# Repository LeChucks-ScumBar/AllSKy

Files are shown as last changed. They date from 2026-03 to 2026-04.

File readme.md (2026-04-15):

# AllSky to Go STSCI Waldbröl
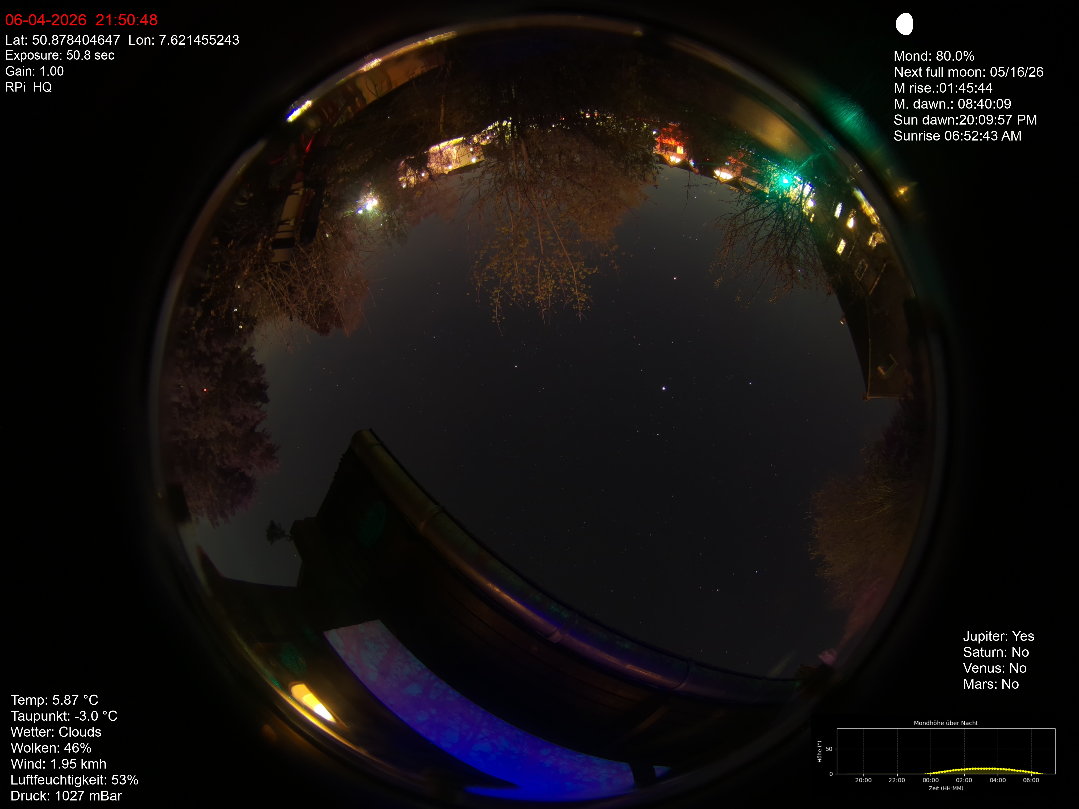
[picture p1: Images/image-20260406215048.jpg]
single image with data


## how to install

copy all files in the home Directory. 

## Setup crontab

````
crontab -e
````

add this two cronjobs

```
*/30 * * * * python ~/allsky/gps_coords.py
0 */1 * * * /home/raspberry/allsky/scripts/moon_height_venv.sh
```

## install skyfield for moon diagram

```
pip3 install skyfield matplotlib numpy
```

if this not work use a virtual environment
```
sudo apt install python3-venv
mkdir -p ~/allsky/venv
python3 -m venv ~/allsky/venv
source ~/allsky/venv/bin/activate
pip install skyfield requests
```

test the moon_height.py script
```
python ~/allsky/scripts/moon_height.py
```
Change crontab entry. moon_height_venv.sh use For skyfield the new use a virtual enviroment 
```
crontab -e
0 */1 * * * /home/raspberry/allsky/scripts/moon_height_venv.sh

```

if this is not working you can use the quick and dirty Methode

```
pip install skyfield --break-system-packages
```

Now you can overlay this image with your camera Picture. Go to your Webbrowser and to your allsky Webpage. Go to the "Overlay Editor" and Chose "add Existing Image Field". In the image menue you can select moon_height.png.

## install gps
For installing the gps-module I have used the install manuel from Allsky_go
[AllskyGo_GPS_install](https://github.com/Chrise-2000/Allsky_Go/blob/main/C_Installation%20Manual%20v3.0.pdf)
Use a usb-gps-module were you can connect with your pi. IF you don´t want to use a or you haven`t an gps-module enter you coordinates in ~/allskygps_coords.txt

## weather data
For overlay weather data I`ve used the open weather module from allsky-modules. You need only a open-weather apy-key. Registration at https://openweathermap.org/ is free, and data can be accessed up to 3,600 times a day at no additional cost.

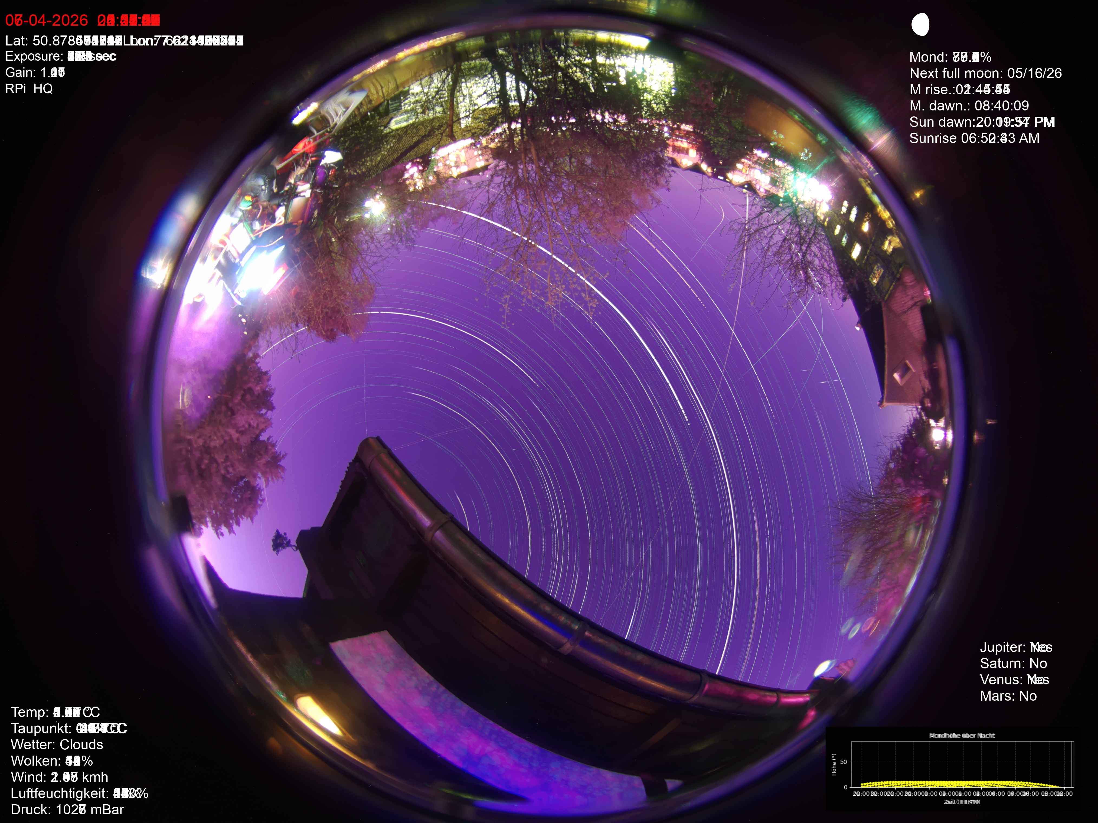
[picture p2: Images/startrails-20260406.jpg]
Startrail

## Material
- [RAspberry Pi 5 4 GB RAM](https://www.amazon.de/Raspberry-Pi-SC1111-5-4Gb/dp/B0CK3L9WD3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)
- [Raspberry PI HQ Camera](https://www.amazon.de/dp/B0BHF4D1QY/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)
- [Camera cable](https://www.amazon.de/dp/B0DHVGGY24/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)
- [Fisheye M12 1,56 mm](https://botland.de/kameraobjektive-fur-raspberry-pi/17066-fisheye-m12-156-mm-objektiv-mit-adapter-fur-raspberry-pi-kamera-arducam-ln031-5904422378349.html)
- [active cooling](https://www.amazon.de/GeeekPi-Aktiver-Raspberry-Aluminum-K%C3%BChlk%C3%B6rper/dp/B0CNVDF2MC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)

or use the POE HAT

- [POE](https://www.amazon.de/Waveshare-HAT-Power-Over-Ethernet/dp/B0CV4MYGMF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)
- [256GB SD card](https://www.amazon.de/dp/B0BFHHKHFK/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) 32GB is also OK
- [AllSky Dome](https://www.amazon.de/dp/B01MZGX7XY/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)
  
## External Links 
External Projects Links were I have used for this project

[Original AllSky](https://github.com/AllskyTeam/allsky)

[AllSky Modules](https://github.com/AllskyTeam/allsky-modules)

[AllSky Go](https://github.com/Chrise-2000/Allsky_Go)

## Images
Version 1 Top, 125 KG Rohr, with ZWO715MC
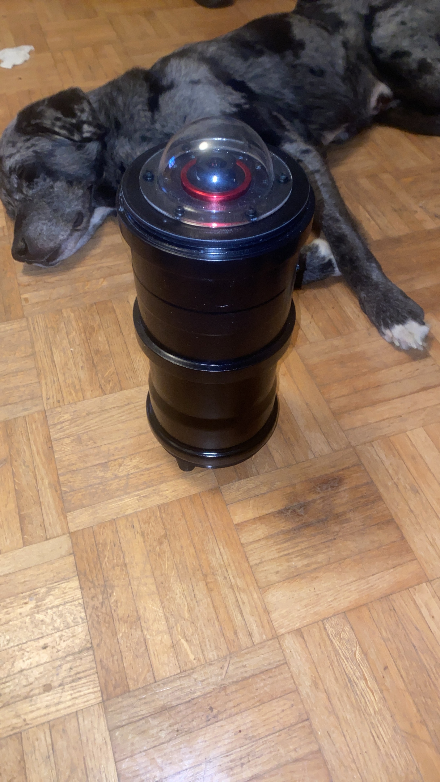
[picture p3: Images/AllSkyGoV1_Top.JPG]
Version 1 Top, 125 KG Rohr, with ZWO715MC


Version 1 Bottom, 125 KG Rohr with ZWO715MC
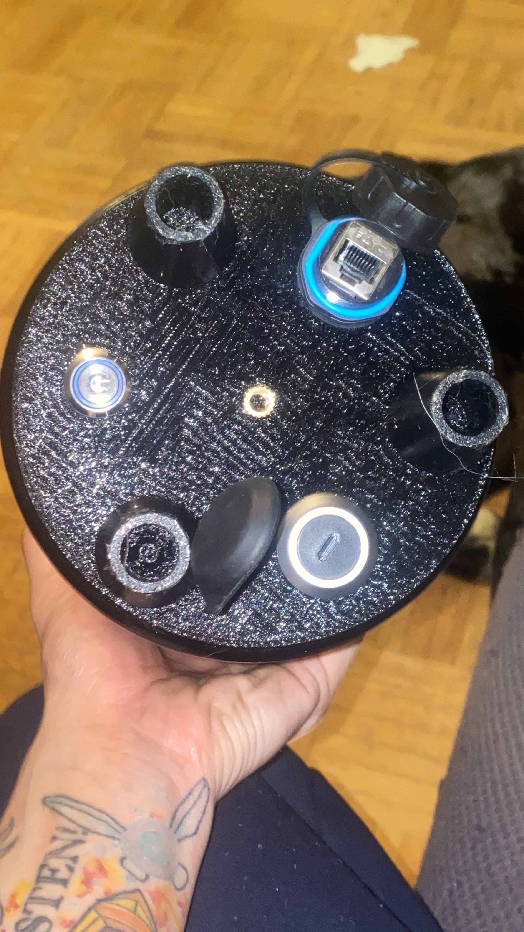
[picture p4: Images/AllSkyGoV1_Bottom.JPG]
Version 1 Bottom, 125 KG Rohr with ZWO715MC


Version 2 with bigger battery and PiHQ camera
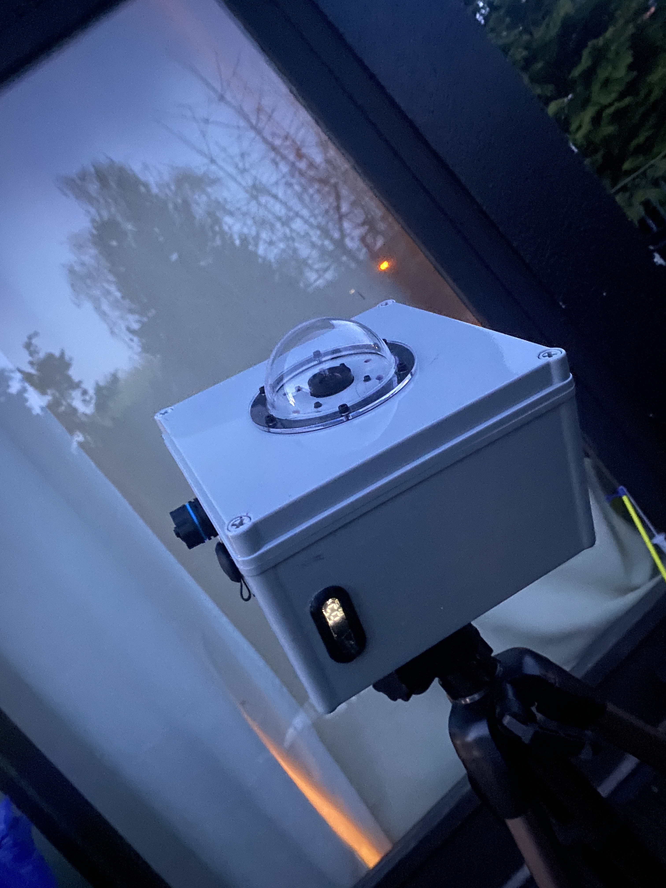
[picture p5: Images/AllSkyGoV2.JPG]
Version 2 with bigger battery and PiHQ camera


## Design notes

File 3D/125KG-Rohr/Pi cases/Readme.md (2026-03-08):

##Pi Cases from makerworld

- Raspberry Pi 5 MACH 1 Gehäuse [inline-style link](https://makerworld.com/de/models/648246-raspberry-pi-5-mach-1-case?from=search#profileId-575928)

- Minimales Raspberry Pi 5 Gehäuse [inline-style link](https://makerworld.com/de/models/106015-minimal-raspberry-pi-5-case?from=search#profileId-456882)

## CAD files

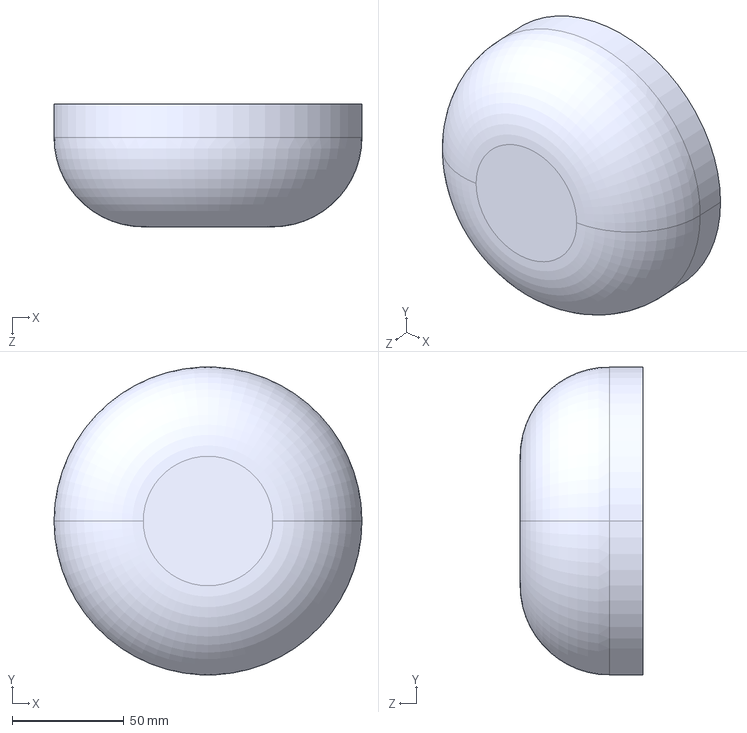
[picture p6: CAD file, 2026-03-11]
3D/125KG-Rohr/schutz.STEP
138.0 x 137.8 x 55.0 mm

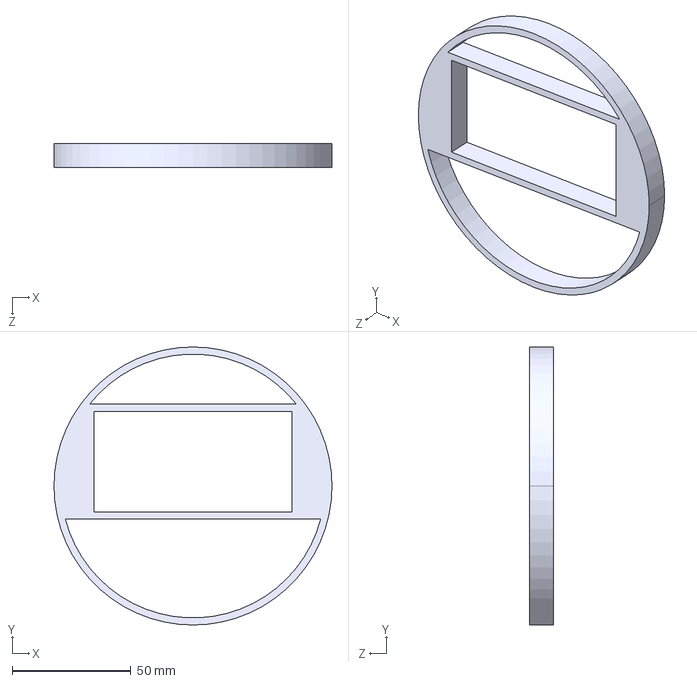
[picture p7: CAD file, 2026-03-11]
3D/125KG-Rohr/akku_halter_TPU.STEP
117.0 x 117.0 x 10.0 mm

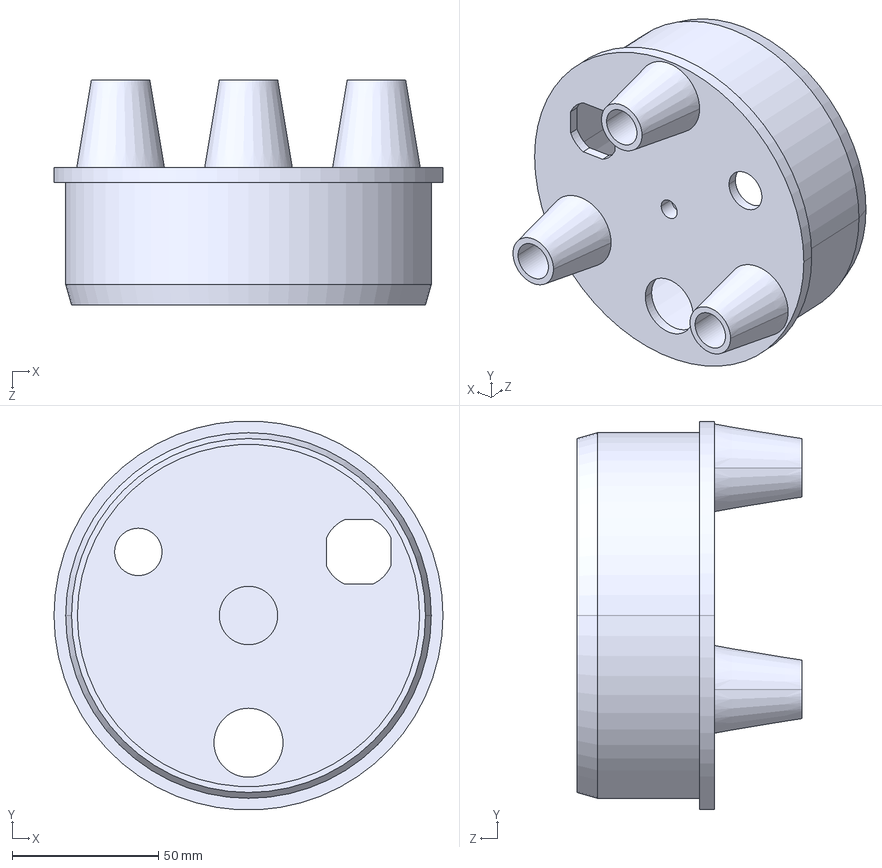
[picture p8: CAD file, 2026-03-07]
3D/125KG-Rohr/Boden.step
133.0 x 132.8 x 77.0 mm

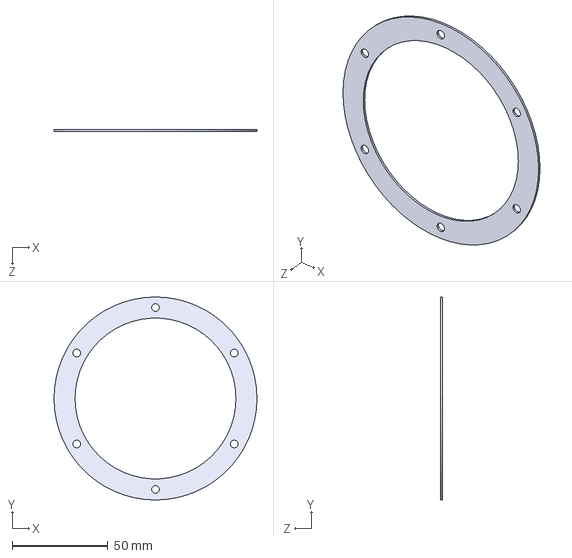
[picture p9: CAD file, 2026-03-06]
3D/125KG-Rohr/dichtung.STEP
106.0 x 106.0 x 1.00 mm

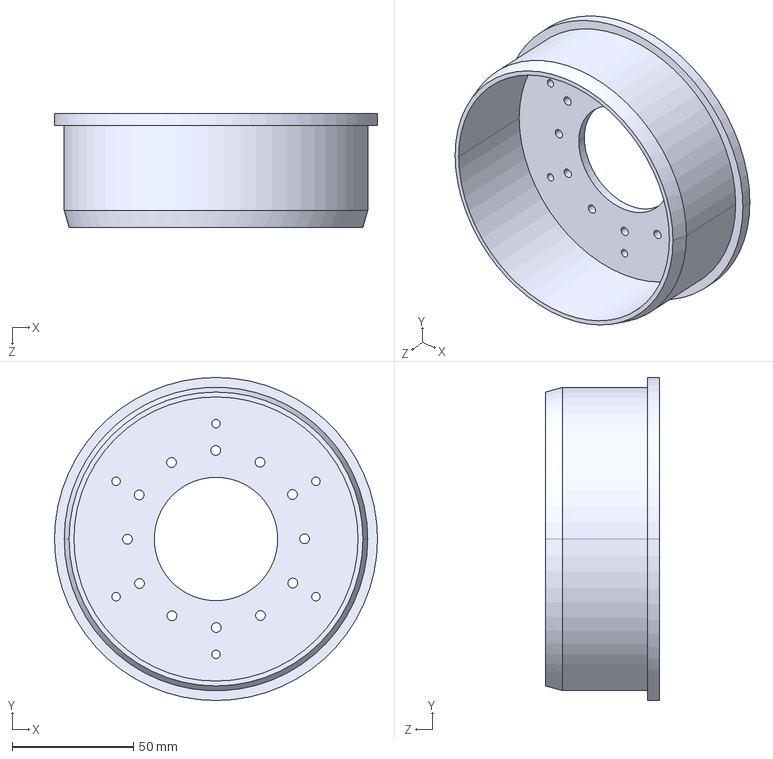
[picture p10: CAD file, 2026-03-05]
3D/125KG-Rohr/Kuppel.STEP
133.0 x 133.0 x 47.0 mm

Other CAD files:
3D/125KG-Rohr/Boden.SLDPRT
3D/125KG-Rohr/Boden.STL
3D/125KG-Rohr/Kuppel.SLDPRT
3D/125KG-Rohr/Kuppel.STL
3D/125KG-Rohr/akku_halter_TPU.SLDPRT
3D/125KG-Rohr/dichtung.SLDPRT
3D/125KG-Rohr/dichtung.STL
3D/125KG-Rohr/schutz.SLDPRT

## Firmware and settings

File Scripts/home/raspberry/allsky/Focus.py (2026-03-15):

from picamera2 import Picamera2
import cv2
import numpy as np

# Kamera starten
picam2 = Picamera2()
picam2.start()

while True:
    # Frame aufnehmen
    frame = picam2.capture_array()

    # Graustufen für Fokusberechnung
    gray = cv2.cvtColor(frame, cv2.COLOR_BGR2GRAY)
    focus = cv2.Laplacian(gray, cv2.CV_64F).var()

    # Fokuswert auf Bild einblenden
    cv2.putText(frame, f"Focus: {focus:.1f}", (20,40),
                cv2.FONT_HERSHEY_SIMPLEX, 1, (0,255,0), 2)

    # Bild anzeigen
    cv2.imshow("Focus Assist", frame)

    # 'q' zum Beenden
    if cv2.waitKey(1) == ord('q'):
        break

cv2.destroyAllWindows()

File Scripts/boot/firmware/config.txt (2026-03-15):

# For more options and information see
# http://rptl.io/configtxt
# Some settings may impact device functionality. See link above for details

# Uncomment some or all of these to enable the optional hardware interfaces
#dtparam=i2c_arm=on
#dtparam=i2s=on
#dtparam=spi=on
usb_max_current_enable=0
# Enable audio (loads snd_bcm2835)
#dtparam=audio=off

#Disable HDMI
hdmi_blanking=2
#disable bluetooth
dtoverlay=disable-bt
#turn off on board sound system
dtparam=audio=off

# Disable ACT LED (green)
# Disable PWR LED (red)
dtparam=act_led_trigger=none
dtparam=act_led_activelow=off
dtparam=eth_led0=4
dtparam=eth_led1=4

# Additional overlays and parameters are documented
# /boot/firmware/overlays/README

# Automatically load overlays for detected cameras
camera_auto_detect=1

# Automatically load overlays for detected DSI displays
display_auto_detect=1

# Automatically load initramfs files, if found
auto_initramfs=1

# Enable DRM VC4 V3D driver
dtoverlay=vc4-kms-v3d
max_framebuffers=2

# Don't have the firmware create an initial video= setting in cmdline.txt.
# Use the kernel's default instead.
disable_fw_kms_setup=1

# Run in 64-bit mode
arm_64bit=1

# Disable compensation for displays with overscan
disable_overscan=1

# Run as fast as firmware / board allows
arm_boost=1

[cm4]
# Enable host mode on the 2711 built-in XHCI USB controller.
# This line should be removed if the legacy DWC2 controller is required
# (e.g. for USB device mode) or if USB support is not required.
otg_mode=1

[cm5]
dtoverlay=dwc2,dr_mode=host

[all]

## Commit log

2026-03-05 3d fies
    [Boden.SLDPRT, Kuppel.SLDPRT, Kuppel.STEP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]
2026-03-05 Verschoben in 3D
    [Boden.SLDPRT, Kuppel.SLDPRT, Kuppel.STEP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]
2026-03-05 add holes
    [Boden.SLDPRT, Kuppel.SLDPRT, Kuppel.STEP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]
2026-03-05 zu M3 Löcher geändert
    [Kuppel.SLDPRT, Kuppel.STEP, Kuppel.STL]
2026-03-06 add dichtung
    [boden2.SLDPRT, dichtung.SLDPRT, dichtung.STEP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]
2026-03-07 add Boden
    [boden2.SLDPRT, boden2.STEP, boden2.STL]
2026-03-08 rename files and add pi cases
    [Boden.SLDPRT, Boden.STL, Boden.step]
2026-03-11 add reduzierter innenhalter für den Akku und schutzkappe
    [akku_halter_TPU.SLDPRT, akku_halter_TPU.STEP, schutz.SLDPRT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]
2026-03-15 add scripts
    [config.txt]
2026-03-16 add settings hq camera
2026-04-11 add moon_height.py script
    [Boden.SLDPRT, Boden.STL, Boden.step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]
